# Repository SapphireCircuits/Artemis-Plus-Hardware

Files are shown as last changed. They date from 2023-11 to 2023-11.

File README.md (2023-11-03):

# Sapphire Circuits Artemis Plus Module

This is a remix of the Sparkfun Artemis module.  It is module pin-for-pin backward compatible with the original module except it has twice the Flash and RAM memory.

### Hardware available through our Kickstarter:
[https://www.kickstarter.com/projects/davewy/artemis-plus-low-power-ai-ml-processing-platform-and-dev-kit](https://www.kickstarter.com/projects/davewy/artemis-plus-low-power-ai-ml-processing-platform-and-dev-kit)

In accordance with the terms of the Attribution-ShareAlike 4.0 International License (http://creativecommons.org/licenses/by-sa/4.0/), the Sapphire Circuits Artemis Plus remix of the SparkFun Artemis Module is distributed under the same license.  

Please review the LICENSE.md file for additional information. 

Attribution:
Original Design Attributed To: SparkFun Electronics
Schematic Designed By: SparkFun Electronics, N. Seidle  (Designer Name As Listed In Schematic Title Block) 
PCB Layout Designed By: SparkFun Electronics, N. Seidle (Designer Name As Listed In Layers)
Original Design Files:  https://github.com/sparkfun/SparkFun_Artemis

Modifications:
The original design has been modified to use the Ambiq Apollo3 Blue Plus instead of the Ambiq Apollo3 Blue Microcontroller.  Both micro-controllers have many pins, signals, and peripheral units in common.  However, the micro-controllers have physically different dimensions as, ball sizes, and the Artemis Plus version has additional pins.  Where possible, these pins were kept the same as to maintain as much compatibility as possible.  The trace and space as well as the individual routing for the signals needed to be adjusted due to differences in the locations and pin sizes. 

The original design files were designed in EAGLE, but for this remix it was imported into Altium Designer.

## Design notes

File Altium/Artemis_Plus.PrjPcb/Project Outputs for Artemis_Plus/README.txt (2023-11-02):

Contact Info:
jared@sapphirecircuits.com

Notes:
IPC 6012 class 2
ENIG Surface Finish
Green solder mask & white silk screen 
2.7mil trace and space.
Board target thickness is to be approximately 0.8mm.  
This design uses Via-In-Pad.  
All through hole vias are to be resin filled and copper capped.
All microvias are to be copper filled.

Directory And File Description:
3D Model
	Artemis Plus 3D Model.pdf - 3D pdf model

BOM
	Artemis_Plus-BOM.xlsx - Bill of materials

CCA
	Artemis_Plus-CCA.PDF - Assembly documentation

Gerber		
	.GTO                Top Overlay                             
	.GTP                Top Paste                               
	.GTS                Top Solder                              
	.GTL                L1 (Top)                                 
	.G1                 L2 (inner layer 1)                                    
	.G2                 L3 (inner layer 2)                                   
	.GBL                L4 (Bot)                                 
	.GBS                Bottom Solder                           
	.GBP                Bottom Paste                            
	.GBO                Bottom Overlay                          
	.GM1                Dimension (Board Outline)                               
	.GM2                Route Tool Path  (Slot)

NC Drill
	Layer Pair : L1(Top) to L4(Bot)  ASCII Plated RoundHoles File : Artemis_Plus-Plated.TXT
	MicroVia : L1(Top) to L2 ASCII Plated RoundHoles File : Artemis_Plus-Plated.TX3
	MicroVia : L3 to L4(Bot) ASCII Plated RoundHoles File : Artemis_Plus-Plated.TX4

ODB
	Artemis_Plus-ODB.zip ODB++ zip file
	
Pick and Place
	Artemis_Plus-PnP.csv - pick and place file

PWB
	Artemis_Plus-PWB.PDF - board fabrication documentation

SCH
	Artemis_Plus-Schematic.PDF - design schematic

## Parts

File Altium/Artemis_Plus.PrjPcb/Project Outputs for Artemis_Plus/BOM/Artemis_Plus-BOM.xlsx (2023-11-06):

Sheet: Part List Report
 |  | Component list |  | Artemis Plus
 |  | Source Data From: | Artemis_Plus.PrjPcb |  | Contact Name: | Jared Mizrahi
 |  | Project: | Artemis_Plus.PrjPcb |  | Phone:
 |  | Variant: | None |  | Email: | jared@sapphirecircuits.com
 |  | Revision: | C
 | Report Date: |  | 11/5/2023 | 10:16 PM
 | Print Date: |  | 2023-11-05 | 22:17:05
# | Quantity | Designator | Comment | Description | Footprint | Manufacturer 1 | Manufacturer Part Number 1 | Supplier 1 | Supplier Part Number 1
1 | 1 | A1 | RGFRA8010110A2T | Chip Antenna, 2.45Ghz, Smt Rohs Compliant: Yes |Walsin RGFRA8010110A2T | RGFRA8010110A2T | Walsin Technologies | RGFRA8010110A2T | Digi-Key | 1292-RGFRA8010110A2TCT-ND
2 | 1 | C1 | 0.47uF | Multilayer Ceramic Capacitor, 0.47 uF, 50 V, ± 2%, C0G (NP0), 0402 [1005 Metric] | 0402-TIGHT-C | Yageo | CC0402KRX7R6BB474 | Digi-Key | 13-CC0402KRX7R6BB474CT-ND
3 | 1 | C2 | 4.7uF | Multilayer Ceramic Capacitor, 4.7 uF, 10 V, ± 20%, X5R, 0402 [1005 Metric] | 0402-TIGHT-C | Samsung | CL05A475MP5NRNC | Digi-Key | 1276-1482-1-ND
4 | 4 | C3, C5, C8, C16 | 2.2uF | Multilayer Ceramic Capacitor, 2.2 uF, 10 V, ± 10%, X5R, 0402 [1005 Metric] | 0402-TIGHT-C | Murata | GRM155R61A225KE01D | Digi-Key | 490-GRM155R61A225KE01DCT-ND
5 | 5 | C4, C12, C13, C14, C15 | 1.0uF | Multilayer Ceramic Capacitor, 1 uF, 6.3 V, ± 10%, X7R, 0402 [1005 Metric] | 0402-TIGHT-C | Murata | GRM155R70J105KA12J | Digi-Key | 490-13339-1-ND
6 | 2 | C6, C7 | 6pF | 0402 6 pF 50 V ±0.5 pF Tolerance C0G/NP0 SMT Multilayer Ceramic Capacitor | 0402-TIGHT-C | Walsin Technologies | 0402N6R0D500CT | Digi-Key | 1292-1348-1-ND
7 | 1 | C11 | 47nF | CAP CER 0.047UF 16V 10% X7R 0402 | 0402-TIGHT-C | Murata | GCM155R71C473KA37D | Digi-Key | 490-6042-1-ND
8 | 1 | C17 | DNP | DNP | 0402-TIGHT
9 | 1 | C18 | 0.5pF | Multilayer Ceramic Capacitor, 0.5 pF, 50 V, ± 0.25pF, C0G (NP0), 0402 [1005 Metric] | 0402-TIGHT-C | Murata | GJM1555C1HR50CB01D | Digi-Key | 490-3081-1-ND
10 | 1 | L1 | 2.2μH | Inductor Power Shielded Wirewound 2.2uH 20% 1MHz Metal 1.7A 0.14Ohm DCR 0806 T/R | DFE201610E-2R2MP2 | Murata | DFE201610E-2R2M=P2 | Digi-Key | 490-17728-1-ND
11 | 1 | L2 | 1.0uH | Inductor Power Chip Shielded Multi-Layer 1uH 20% 1MHz Ferrite 1.6A 0.107Ohm DCR 0805 T/R | LQM21PN1R0MEHD | Murata | LQM21PN1R0MEHD | Digi-Key | 490-15984-1-ND
12 | 1 | L3 | 2.7nH 900mA 70 mOhm | IND 2.7NH 900MA 70 MOHM | 0402-TIGHT-L | Murata | LQG15WZ2N7S02D | Digi-Key | 490-15274-1-ND
13 | 1 | L4 | 2nH 900mA 120mOhm | FIXED IND 2NH 900MA 120 MOHM SMD | 0402-TIGHT-L | Murata | LQG15HN2N0S02D | Digi-Key | 490-6558-1-ND
14 | 1 | R2 | 0 | Res Thick Film 0402 0 Ohm Jumper Molded SMD Paper T/R | 0402-TIGHT-R | Stackpole Electronics | RMCF0402ZT0R00 | Digi-Key | RMCF0402ZT0R00CT-ND
15 | 1 | U1 | AMBIQ-APOLLO3-BLUE-PLUS | Apollo3 Blue Plus 96 MHz Cortex M4F, 2048 KB Flash, 768 KB RAM, BLE 5, BGA | BGA-104-5.3X4.3MM - Sprite-mixed-0.2-0.19 - 3DModel | Ambiq Micro | AMA3B2KK-KBR | Digi-Key | 5128-AMA3B2KK-KBRCT-ND
16 | 1 | Y1 | 32MHz | Crystal 32 Mhz 6PF SMD | ECS-320-6-37B2-CKM-TR | ECS International | ECS-320-6-37B2-CKM-TR | Digi-Key | 50-ECS-320-6-37B2-CKM-TRCT-ND
Approved |  |  |  | Notes

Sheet: Project Information
Project Full Path | C:\Users\Jam\Desktop\projects\SDGD\Artemis_Plus\Altium Files\Imported Artemis_Plus.PrjPcb\Artemis_Plus.PrjPcb
Project Filename | Artemis_Plus.PrjPcb
Variant Name | None
Data-Source Filename | Artemis_Plus.PrjPcb
Data-Source Full Path | C:\Users\Jam\Desktop\projects\SDGD\Artemis_Plus\Altium Files\Imported Artemis_Plus.PrjPcb\Artemis_Plus.PrjPcb
Title | Bill of Materials for Project [Artemis_Plus.PrjPcb] (PCB Document : Artemis_Plus.PcbDoc)
Total Quantity | 24
Report Time | 10:16 PM
Report Date | 11/5/2023
Report Date & Tine | 11/5/2023 10:16 PM
Output Name | Bill of Materials
Output Type | BomReport
Output Generator Name | BOM
Output Generator Description | Bill of Materials
Total Actual Price | <Parameter TotalActualPrice not found>
Total Target Price | <Parameter TotalTargetPrice not found>

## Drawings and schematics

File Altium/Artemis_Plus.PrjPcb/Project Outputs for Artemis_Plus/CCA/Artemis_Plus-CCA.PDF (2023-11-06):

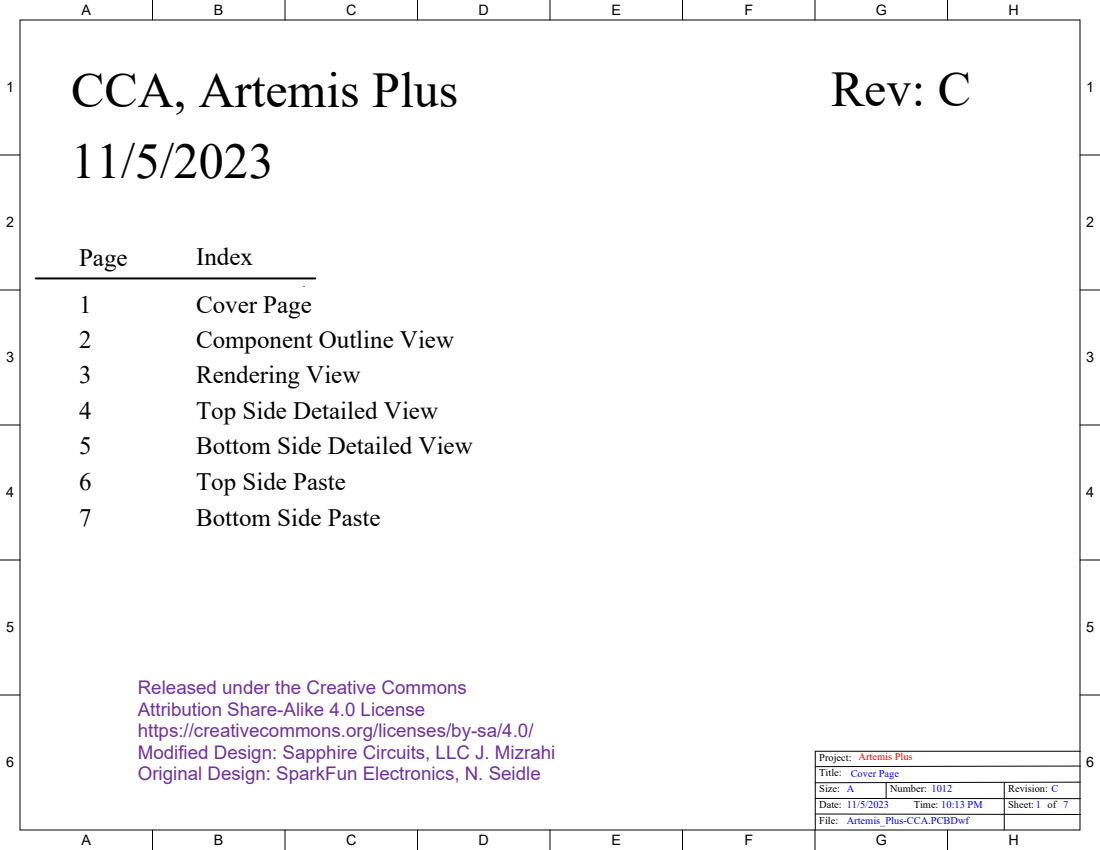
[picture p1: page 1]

Released under the Creative Commons
Attribution Share-Alike 4.0 License
https://creativecommons.org/licenses/by-sa/4.0/
Modified Design: Sapphire Circuits, LLC J. Mizrahi
Original Design: SparkFun Electronics, N. Seidle

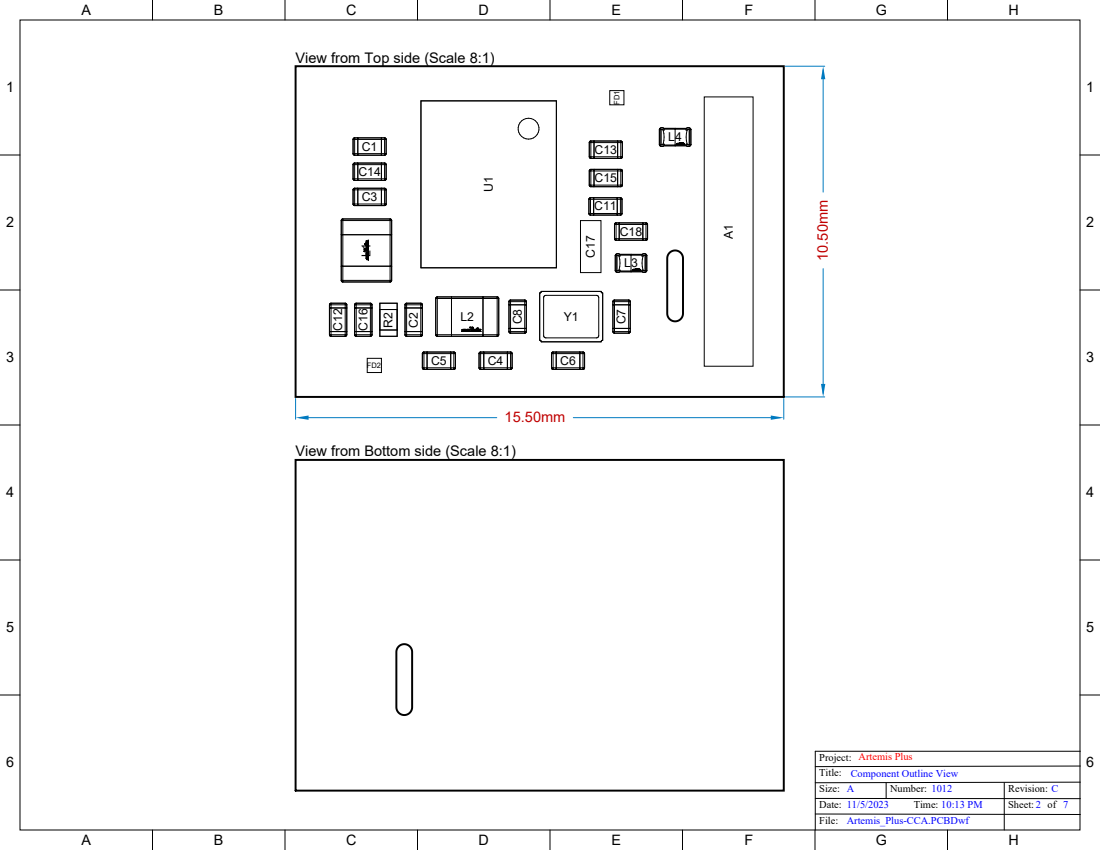
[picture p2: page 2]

View from Top side (Scale 8:1)

View from Bottom side (Scale 8:1)

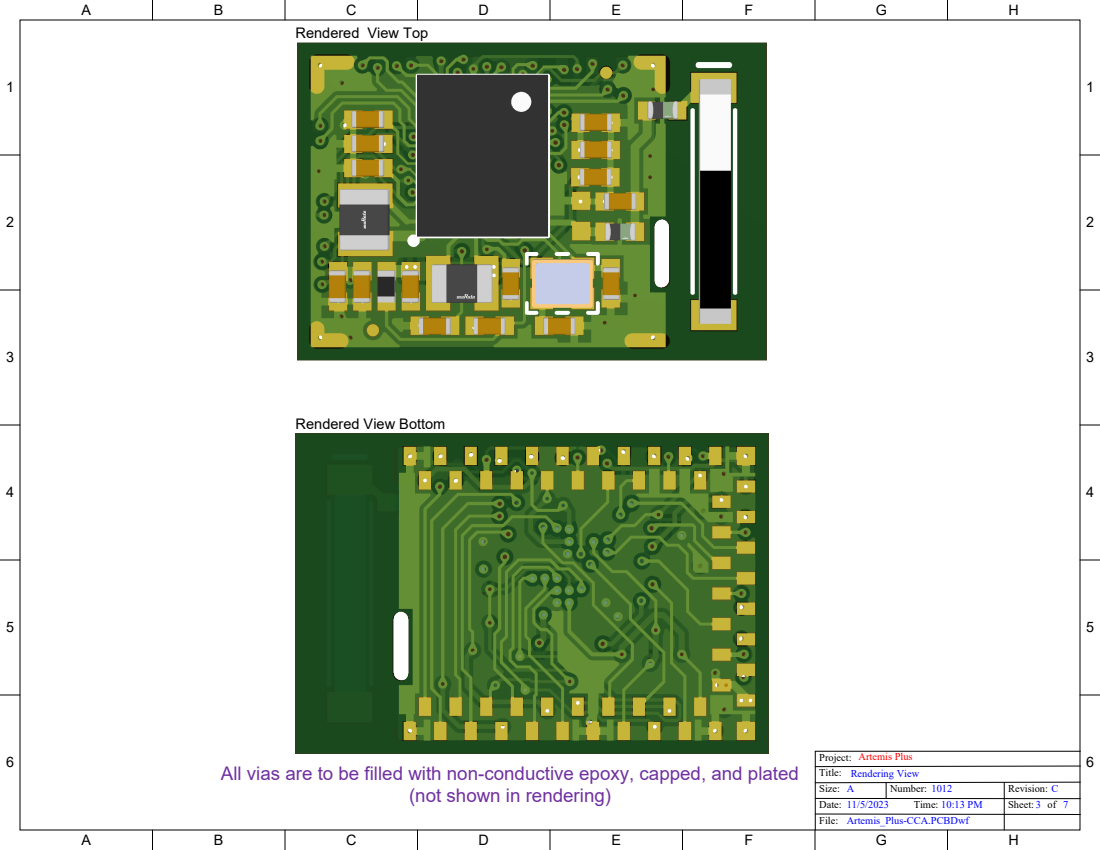
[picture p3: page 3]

All vias are to be filled with non-conductive epoxy, capped, and plated

(not shown in rendering)

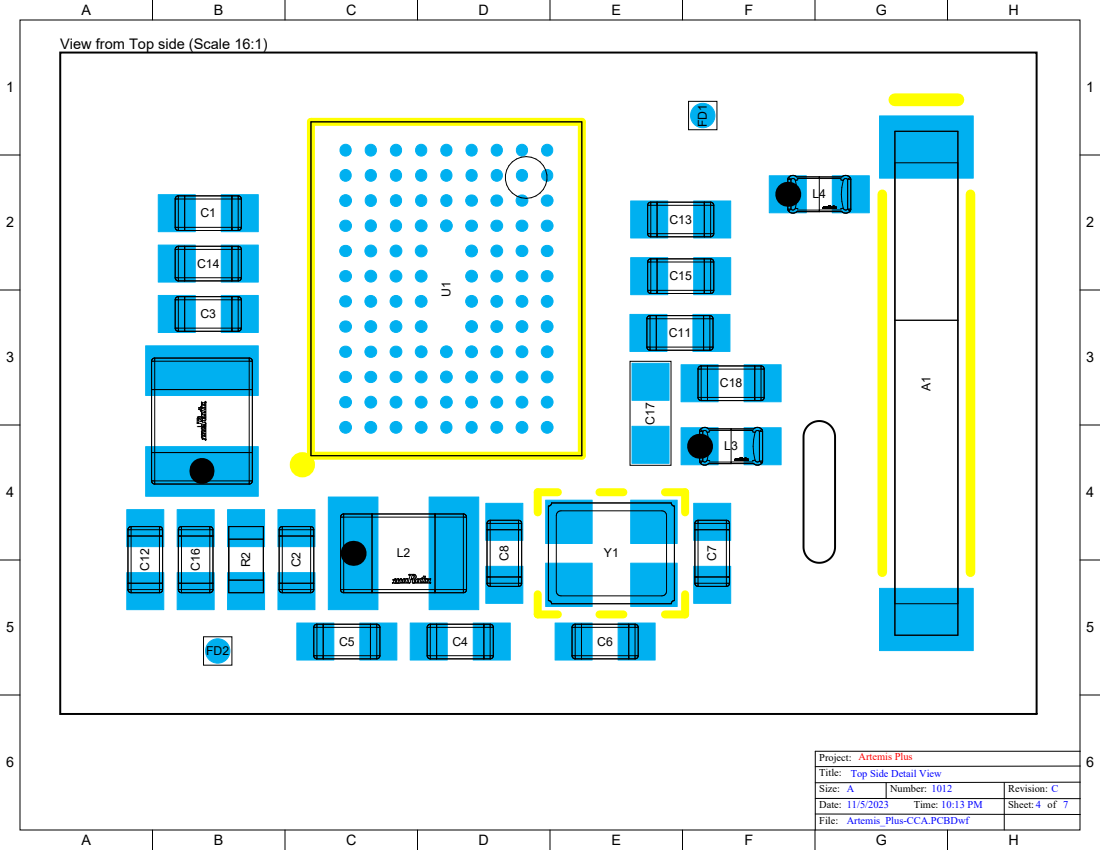
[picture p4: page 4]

View from Top side (Scale 16:1)

Artemis Plus
Top Side Detail View

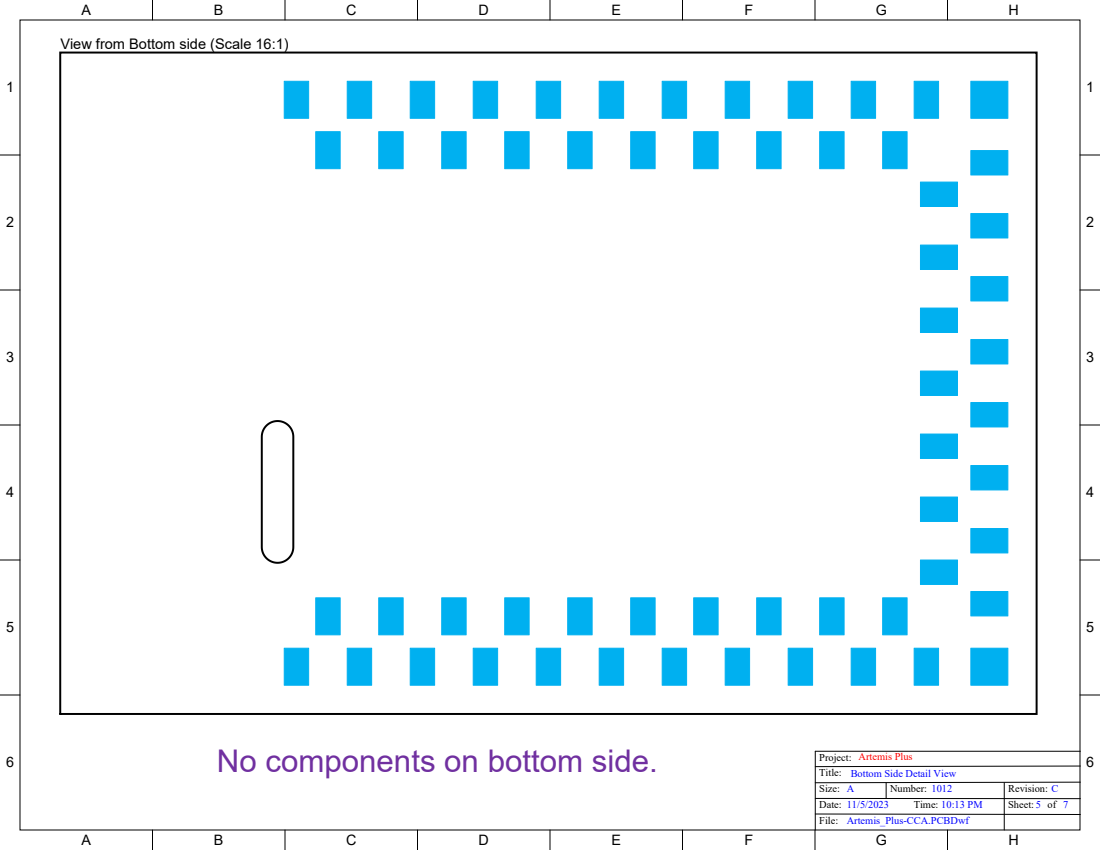
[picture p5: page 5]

View from Bottom side (Scale 16:1)

No components on bottom side.

Artemis Plus
Bottom Side Detail View

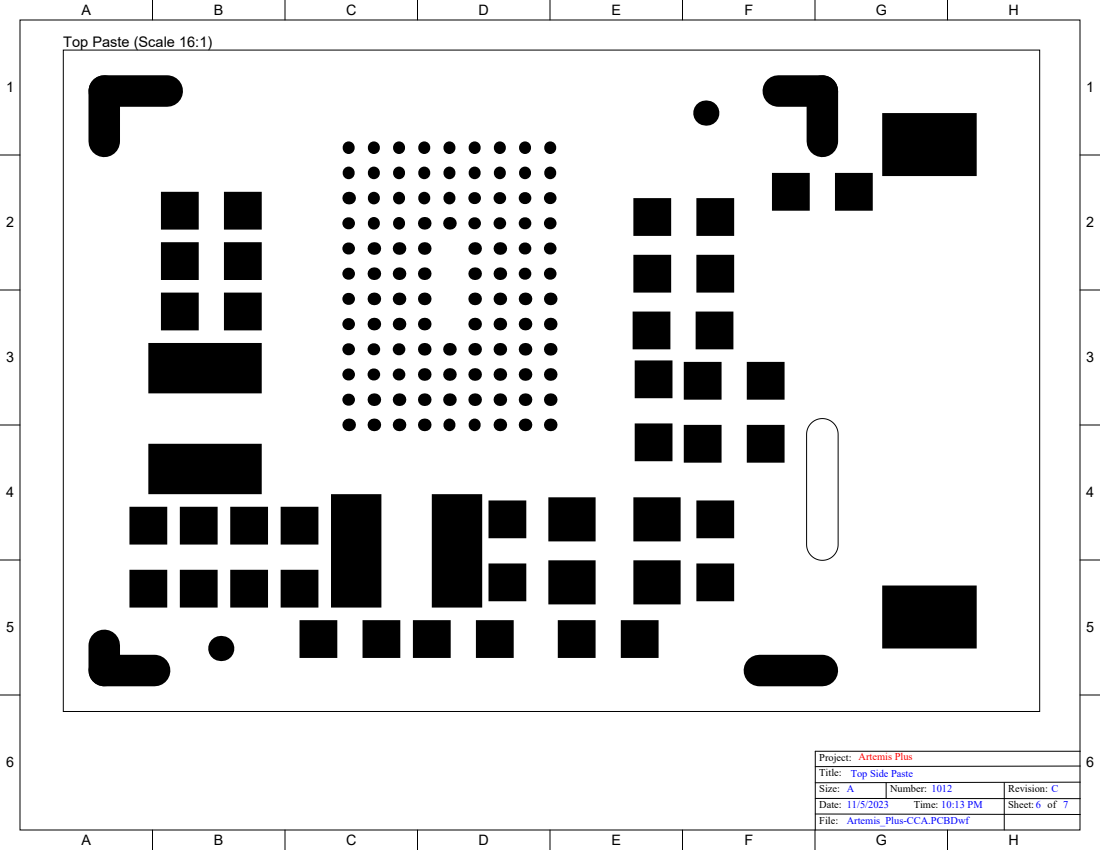
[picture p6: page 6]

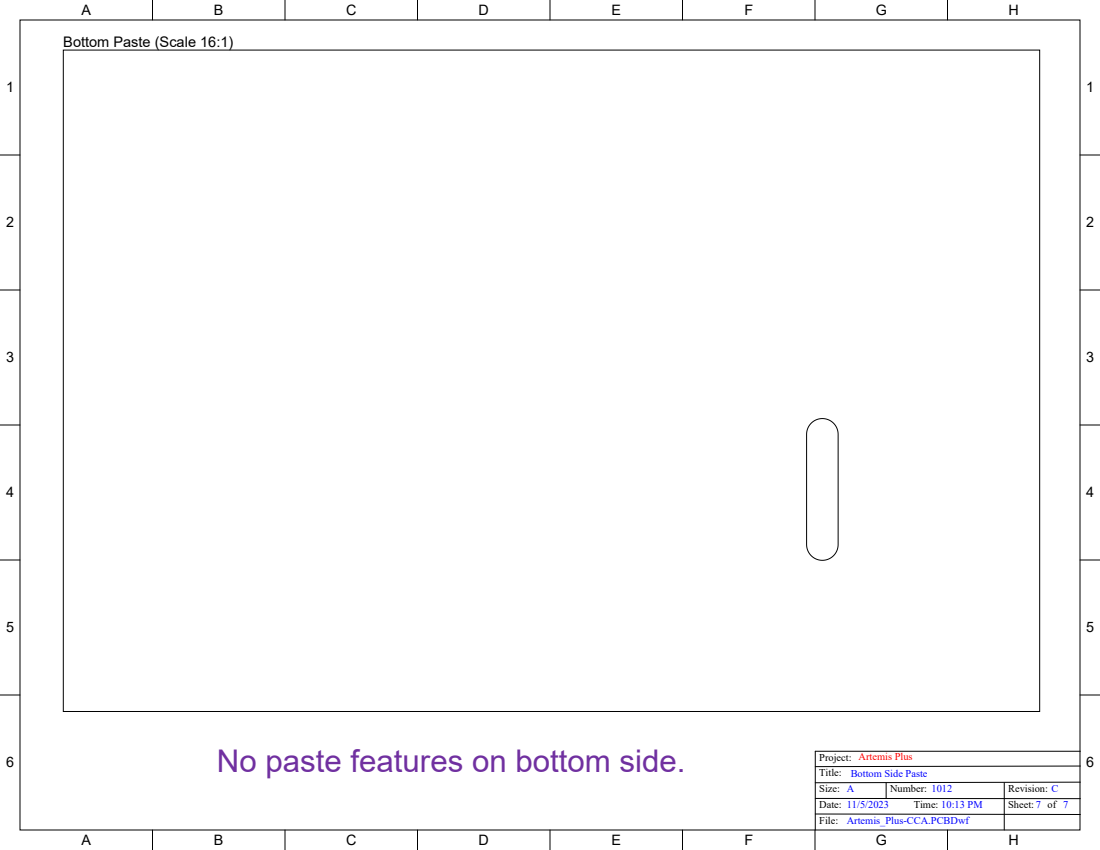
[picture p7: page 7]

No paste features on bottom side.

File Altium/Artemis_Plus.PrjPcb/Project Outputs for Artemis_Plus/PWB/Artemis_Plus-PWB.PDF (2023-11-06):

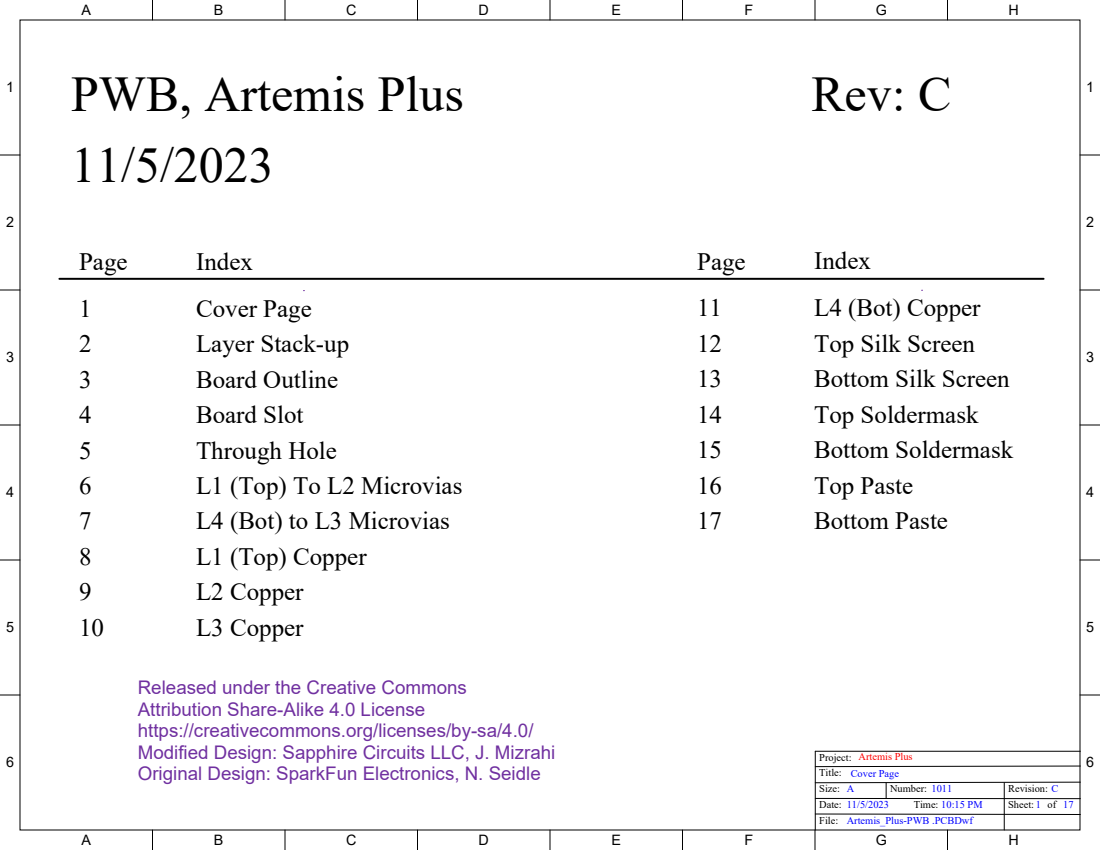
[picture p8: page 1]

Released under the Creative Commons
Attribution Share-Alike 4.0 License
https://creativecommons.org/licenses/by-sa/4.0/
Modified Design: Sapphire Circuits LLC, J. Mizrahi
Original Design: SparkFun Electronics, N. Seidle

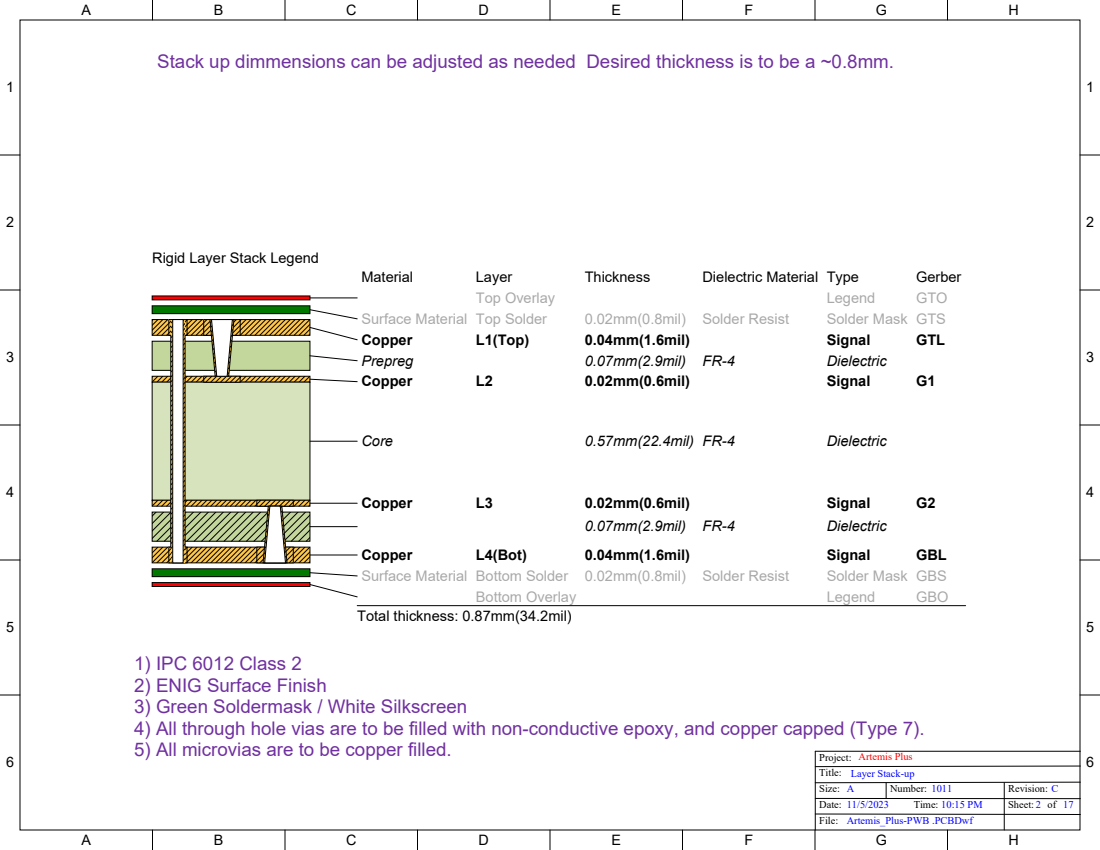
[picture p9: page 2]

Stack up dimmensions can be adjusted as needed Desired thickness is to be a ~0.8mm.

Rigid Layer Stack Legend

1) IPC 6012 Class 2
2) ENIG Surface Finish
3) Green Soldermask / White Silkscreen
4) All through hole vias are to be filled with non-conductive epoxy, and copper capped (Type 7).
5) All microvias are to be copper filled.

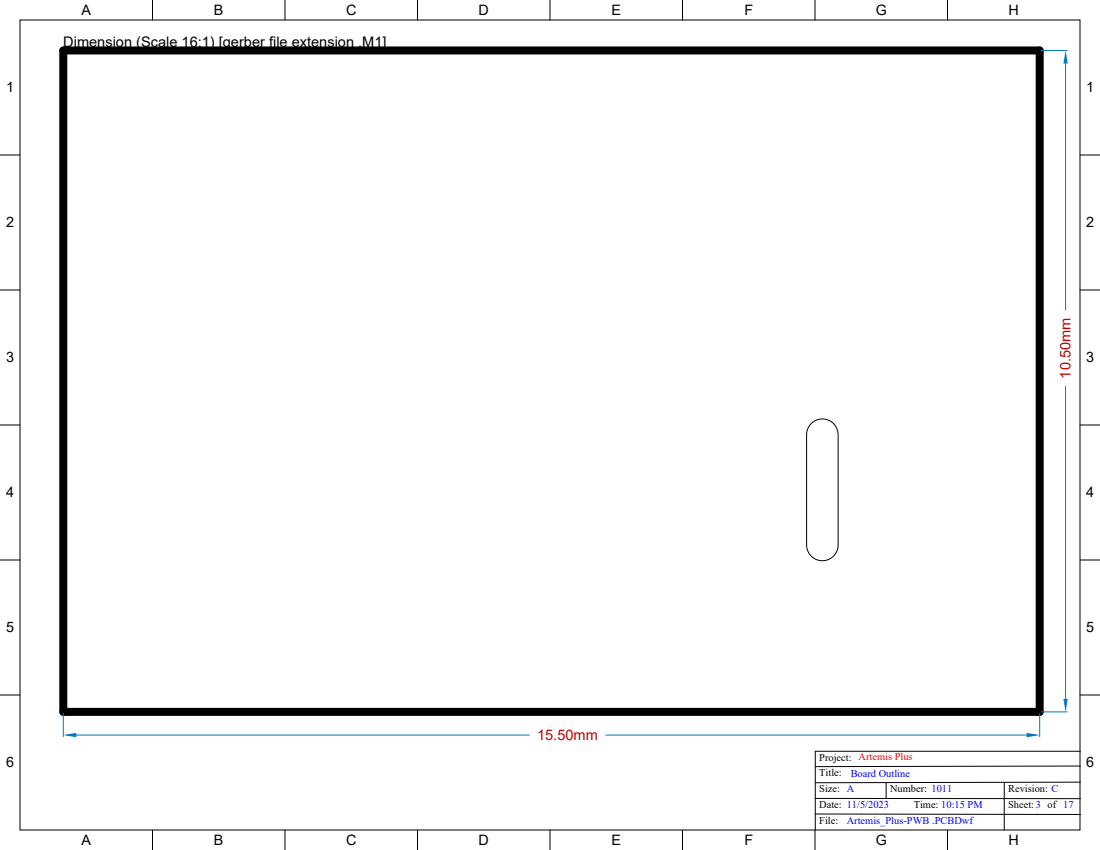
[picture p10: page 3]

Dimension (Scale 16:1) [gerber file extension .M1]

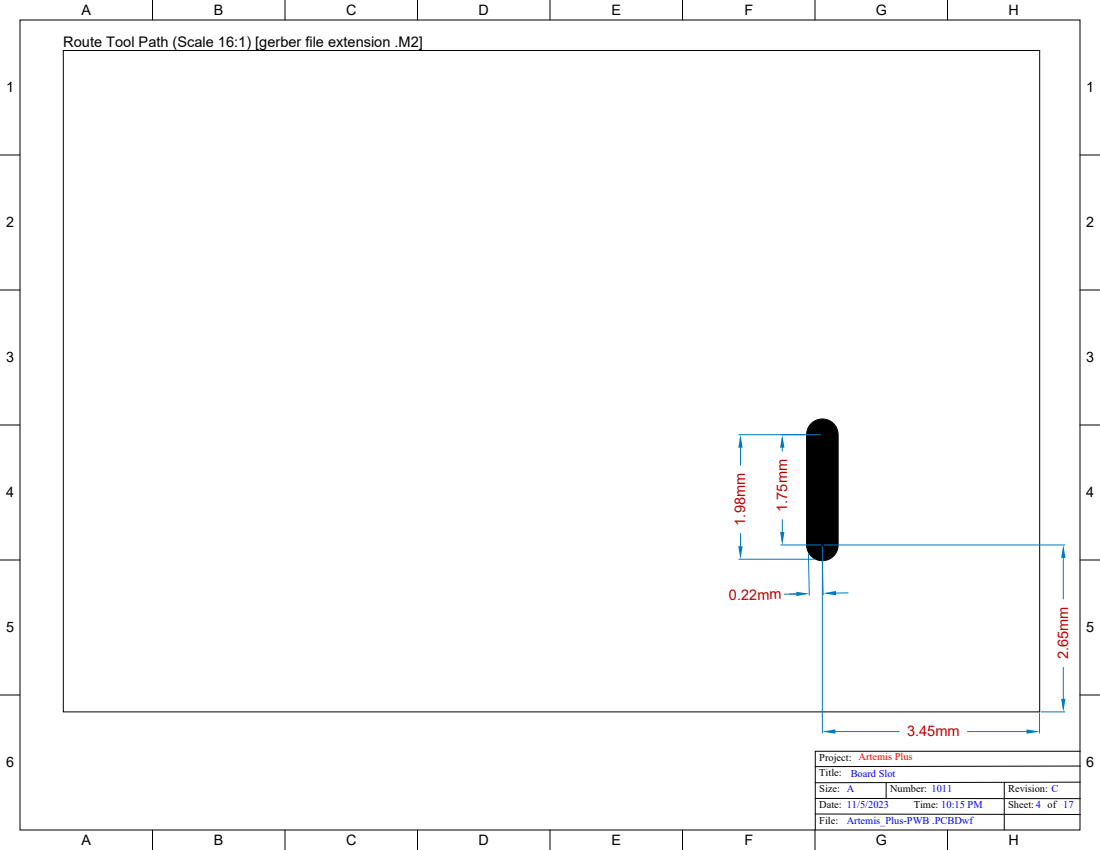
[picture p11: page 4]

Route Tool Path (Scale 16:1) [gerber file extension .M2]

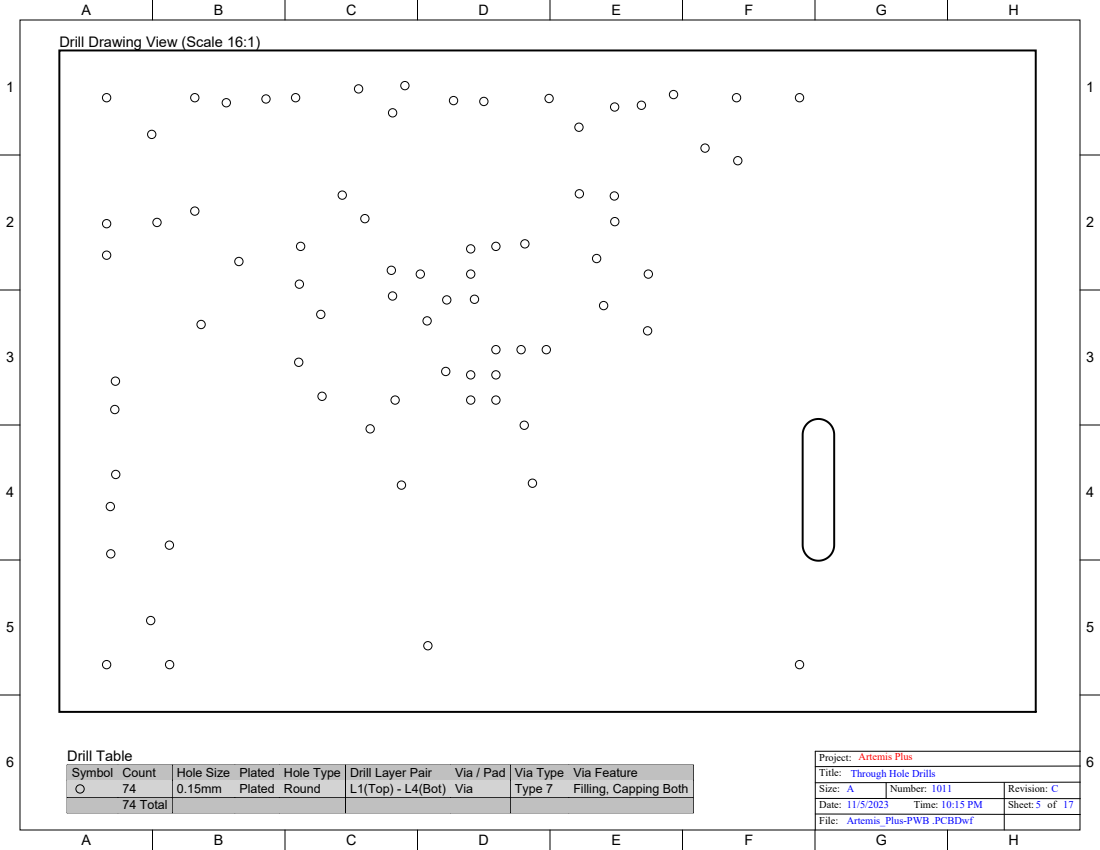
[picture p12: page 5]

Drill Drawing View (Scale 16:1)

Symbol | Count | Hole Size | Plated | Hole Type | Drill Layer Pair | Via / Pad | Via Type | Via Feature

74 | 0.15mm | Plated | Round | L1(Top) - L4(Bot) | Via | Type 7 | Filling, Capping Both
74 Total


Drill Drawing View (Scale 16:1)

All microvias are to
be copper filled.

Hole Size | Plated | Hole Type | Drill Layer Pair | Via / Pad

47 | 0.12mm | Plated | Round | [UVIA] L1(Top) - L2 | Via
47 Total


Drill Drawing View (Scale 16:1)

All microvias are to
be copper filled.

Hole Size | Plated | Hole Type | Drill Layer Pair | Via / Pad

29 | 0.12mm | Plated | Round | [UVIA] L3 - L4(Bot) | Via
29 Total







No silkscreen features on bottom PCB





No paste features on bottom PCB

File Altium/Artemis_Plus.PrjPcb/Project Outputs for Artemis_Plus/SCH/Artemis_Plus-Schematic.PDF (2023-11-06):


J 3 | H 1 1
G 1 | H 1 2
